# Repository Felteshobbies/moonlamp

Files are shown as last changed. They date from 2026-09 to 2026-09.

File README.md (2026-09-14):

# Moon Lamp

A 3D-printed wall lamp that shows the **real, current phase of the moon**.

**Firmware is developed with the help from AI-**

**Printable files:** [Moon Wall Lamp with Moonphase Simulation](https://www.printables.com/model/1840057-moon-wall-lamp-with-moonphase-simulation)

A ring of RGBW LEDs lights the moon relief from the side. The relief is domed —
it rises 20 mm towards the centre — so light entering from one side is blocked
from reaching the other. That turns a brightness gradient into an actual
terminator, and the crater rims catch light beyond the shadow line exactly the
way they do in photographs of the real moon.

A Raspberry Pi Pico W computes sun and moon positions on the device and drives
the ring. No cloud service, no API key; Wi-Fi is used only to set the clock.

> **Status:** the lamp works. The firmware runs on hardware, and the optical
> and astronomical parts are covered by tests that run on a PC without any
> hardware attached. See [Status](#status) for what is still rough.

---

## Why the dome matters

The original design has a flat relief. With a flat disc, the far side of the
moon still receives about **10 %** of the light from the LEDs opposite — the
disc gets dimmer towards the far edge, but it never goes dark, so every phase
reads as "full moon, unevenly lit".

With the 20 mm dome, the shadow side drops below **0.01 %**. That is the whole
trick, and it is what makes phases legible.

The profile is conical rather than a spherical cap, which turned out to be
better on two counts: the shadow edge is sharper, and a cone is a
[developable surface][dev] — so an already printed flat relief can in principle
be warmed and formed into it, which a spherical cap cannot.

[dev]: https://en.wikipedia.org/wiki/Developable_surface

Those figures come from an optical simulation of the real relief: the STL is
rasterised into a height field, point lights are placed on the ring, and shadows
are cast with a horizon sweep per LED. The dome height, the profile and the
`ARC_TABLE` in the firmware were all chosen from that, not guessed.

---

## Repository layout

| | |
|---|---|
| [`firmware/`](firmware/) | MicroPython for the Pico W: ephemeris, rendering, dithering, PIO LED driver, web interface |
| [`installer/`](installer/) | A single executable that flashes a blank Pico and updates it later |
| [`cad/`](cad/) | FreeCAD sources of the revised frame and the PrusaSlicer projects |
| [`models/`](models/) | Where to get the printable files — **the STLs are not in git**, see [models/README.md](models/README.md) |

The model files are deliberately kept out of version control: together they are
about 1.3 GB and four of them are over GitHub's 100 MB per-file limit. They are
distributed through Printables instead.

---

## The lamp

### Parts

| Part | Notes |
|---|---|
| Raspberry Pi **Pico W** | The W matters — Wi-Fi is needed for the clock |
| SK6812 **RGBW** strip | Roughly 1.35 m. The white channel keeps the moon white; RGB-only looks dirty on grey relief and draws about three times the current |
| 5 V / 4 A supply | 40 RGBW LEDs draw 2.9 A at full white, far less in normal use |
| 74AHCT125 level shifter | **Not optional** — the Pico drives 3.3 V, the strip expects 0.7 × VDD |
| 330 Ω resistor | In series at the level shifter output |
| 1000 µF capacitor | Across the supply at the first LED |
| 3 momentary buttons | Optional — program, brighter, dimmer |

At 33 mm pitch, **40 LEDs** fill the r = 209 mm ring: 1313 mm of circumference
leaves a 26 mm gap at the seam. 39 would leave a visible 59 mm.

Feed 5 V in at **two points**, at the seam and opposite it. That halves the
copper path from 1.31 m to 0.65 m; otherwise the far side is visibly warmer in
white. Pico and strip grounds must be connected.

### Programs

| | | |
|---|---|---|
| P0 | Demo | Every state at speed, one lunation per minute. Needs neither network nor clock |
| P1 | Moon phase | The current phase, visible around the clock |
| P2 | Real moon | Like P1, but only while the moon is actually above your horizon; brightness and colour follow its altitude |
| P3 | Colour cycle | Full moon with a slowly drifting tint, white still carrying it |
| P4 | Night light | The dimmest warm white the hardware can hold across the whole ring |
| P5 | Manual | Moon phase and an explicit red/green/blue/white mix, by hand |
| P6 | Spectrum | The whole colour wheel at full saturation, one turn every seven minutes |
| P7 | Rainbow | The entire spectrum around the ring at once, turning. Everything the strip can do |

Earthshine on the dark side is simulated as well, and a red moon can be
scheduled for eclipse dates.

### Setting it up

On first boot the Pico opens its own Wi-Fi network and serves a setup page —
no cable needed after flashing. After that there is a web interface for
program, brightness, earthshine, ring geometry and output mode.

```bat
python -m pip install mpremote

REM copy the code, then configure from a phone
python firmware\tools\provision.py --port COM5

REM or preset everything right away
python firmware\tools\provision.py --port COM5 --ssid MyNetwork ^
    --password secret --lat 51.2 --lon 6.8 --leds 40
```

Details, wiring and the full parameter list: [firmware/README.md](firmware/README.md).

**Or use the installer.** A single executable takes a factory-fresh Pico all
the way to a running lamp: it flashes MicroPython, writes the firmware, asks for
Wi-Fi and where pixel 0 sits, and opens the lamp in your browser. It carries
everything it needs, so no Python, no `pip` and no network are required. The
same tool updates the lamp later, pulling newer firmware from this repository's
releases. See [installer/README.md](installer/README.md).

Either way it is no rocket science, but some experience with microcontrollers
and electronics is helpful.

---

## Tests

Everything that does not need hardware is tested on a PC:

```bat
python firmware\tests\test_ephemeris.py   REM astronomy against known quantities
python firmware\tests\test_render.py      REM arc shape, colour, dithering
python firmware\tests\test_system.py      REM time zones, config, PIO bit timing
python firmware\tests\test_web.py         REM HTTP parsing, form and route consistency
```

The ephemeris is checked against equinoxes and solstices, the synodic month,
perigee and apogee distances, and the fact that a full moon culminates at
midnight. Long-term drift over 20 years is 0.01 days per lunation.

---

## Status

* The firmware runs on real hardware. Wi-Fi, the web interface, the PIO driver
  and the buttons all work.
* **Temporal dithering over DMA** is implemented but has not been field-tested.
  It is off by default and the lamp falls back to the blocking output path if
  DMA is unavailable.
* There is no over-the-air update yet; new code goes in over USB.
* The installer executable is unsigned, so Windows SmartScreen will warn about
  it. Code signing is the only real fix and costs money; until then the folder
  build and the ZIP are flagged less often than the single file.

---

## License

Two licenses, because this repository holds two different kinds of work:

* **Software** (`firmware/`) — [MIT](LICENSE).
* **Models** (`cad/`, `models/`) — [CC BY-NC-SA 4.0](LICENSE-MODELS.md),
  inherited from the original design.

The lamp is a remix of **Illuminated Moon Wall Lamp** by
[DazedDice](https://www.printables.com/@DazedDice), by way of the
[remix](https://www.printables.com/model/1015789-illuminated-moon-wall-lamp-remix)
by [deimosfr](https://www.printables.com/@deimosfr_1155564). Full attribution
in [LICENSE-MODELS.md](LICENSE-MODELS.md).

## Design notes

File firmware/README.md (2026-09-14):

# Moon Lamp — firmware for the Raspberry Pi Pico W

Drives an SK6812 RGBW ring inside the frame of the domed moon lamp. It computes
the real moon phase from NTP time, maps it to an arc of light and a colour, and
is controlled either by three buttons or from a browser.

> **State of things.** The lamp runs: Wi-Fi, the web interface, the PIO driver
> and the buttons all work on real hardware. The astronomy, frame composition,
> dithering, time zone handling and configuration are plain Python and are
> checked on a PC against known quantities — see [Tests](#tests). The one part
> that has not been through a field test is **temporal dithering over DMA**;
> it is off by default and falls back safely.

---

## Hardware

| Part | Value |
|---|---|
| Controller | Raspberry Pi Pico **W** (Wi-Fi is needed for NTP) |
| LED strip | SK6812 RGBW, GRBW byte order, 33 mm pitch |
| LED count | 40 on the ring (r = 209 mm, 1313 mm circumference, 9° per LED) |
| Level shifter | 74AHCT125 or 74AHCT14 — **mandatory** |
| Data line | 330 Ω in series, right at the level shifter |
| Buffer | 1000 µF across the strip supply at the first LED |
| Power supply | 5 V / 4 A (40 × 4 × 18 mA ≈ 2.9 A at full white) |

At 33 mm pitch, 40 LEDs leave a 26 mm gap at the seam. 39 would leave a visible
59 mm, so 40 is the count the ring wants.

**The level shifter is not a luxury.** The Pico outputs 3.3 V, and the WS28xx
family wants roughly 0.7 × VDD for a logic high. Without one it often works —
but temperature-dependently and unreliably. This is the single most common
reason a rebuild misbehaves.

Feed 5 V in at **two points**: at the seam and at the opposite point of the
ring. That halves the copper path from 1.31 m to 0.65 m; otherwise the far side
is visibly warmer in white.

The Pico and the strip must share a ground connection.

### Default pin assignment (changeable in `config.json`)

| Signal | GPIO |
|---|---|
| LED data | 16 |
| Button: program | 12 |
| Button: brighter | 13 |
| Button: dimmer | 14 |

Buttons switch to ground; the internal pull-ups are enabled, so no external
resistors are needed.

---

## Installation

Flash MicroPython for the Pico W first (UF2 from micropython.org), then:

```bat
python -m pip install mpremote

REM Copy the code only, configure from a phone afterwards
python firmware\tools\provision.py --port COM5

REM Or preset everything right away
python firmware\tools\provision.py --port COM5 ^
    --ssid MyNetwork --password secret ^
    --lat 51.2 --lon 6.8 --utc-offset 1 --leds 40
```

### First-time setup from a phone

With no valid Wi-Fi credentials — or when the **program button is held** during
power-up — the Pico opens a network of its own:

1. Join the Wi-Fi network `Moon Lamp Setup`
2. Open `http://192.168.4.1`
3. Fill in the form and save; the lamp restarts

The ring breathes slowly in blue while this is going on, so the state is
recognisable across the room.

Once connected, the **last octet of the IP address** is blinked out as points of
light on the ring — that way the lamp can be found without opening the router's
interface. The hostname is set over DHCP; whether `moonlamp.local` resolves
depends on your router, and on Windows without Bonjour it usually does not.

---

## Controls

| Button | Short press | Long press |
|---|---|---|
| Program | Next program, acknowledged by N points of light | Calibrate the angle offset |
| Brighter | One brightness step up | |
| Dimmer | One step down | |

Brightness steps: 9 % / 15 % / 25 % / 40 % / 65 % / 100 %, in *perceived*
brightness. They are spaced perceptually rather than linearly, because a linear
scale is unusable at the bottom and wasteful at the top.

The lowest step is set by the hardware, not by taste. With 8 bits per channel,
the dimmest level at which *every* LED still lights is one count — 1/255 of the
light, which is 9 % perceived. Below that the ring does not get dimmer, it
thins out into isolated lit pixels.

### Where pixel 0 sits

Where the first LED of the strip ended up after gluing is known only to whoever
glued it. Without that, the crescent points the wrong way.

**Read the rim like a clock face**, looking at the lamp from the front: 12 at
the top, 3 on the right, 6 at the bottom, 9 on the left. The browser asks for
exactly that, plus whether the LED numbers run clockwise or counter-clockwise
from there — follow the arrow printed on the strip.

The default is **6 o'clock**, because the cable channel leaves at the bottom
and the strip's closing gap is least visible there.

Internally the value is still an angle in degrees (`led_offset`: 0 = right,
90 = top, 180 = left, 270 = bottom), which is what the setup portal and
`provision.py` take. The clock positions are just the readable form of the same
number, and a strip that does not start on an hour can still be trimmed with
the ±1 LED buttons.

#### If you do not know which LED is the first one

Long-press the program button, or press "Find pixel 0" in the browser. A single
point lights up: the LED that the current setting believes sits at **6 o'clock**.
Step it with brighter/dimmer, or with the ±1 LED buttons on the page, until the
lit LED really is at the bottom — then the setting is correct. Press the program
button again to leave. The value is written 10 s later, to spare the flash.

Note what this avoids: you never have to work out which physical LED is number
zero, which is the normal situation once the strip is in the frame.

### Programs

| | Name | Needs network | Needs location |
|---|---|---|---|
| P0 | Demo — every state at speed, one lunation in 60 s | no | no |
| P1 | Moon phase — live phase, always visible | yes | no |
| P2 | Real moon — only while it is actually in the sky | yes | yes |
| P3 | Colour cycle — full moon with a drifting tint | no | no |
| P4 | Night light — warm residual light, whole ring | no | no |
| P5 | Manual — phase and an RGBW mix from the browser | no | no |
| P6 | Spectrum — the full colour range, very slowly | no | no |
| P7 | Rainbow — the whole spectrum around the ring, turning | no | no |

**P3 and P6** are the same idea at two strengths. P3 keeps white as the base
and only tints it, so the disc still reads as a moon; one turn takes 90 s. P6
drives the wheel at full saturation with a 10 % white floor, and takes seven
minutes for a turn — slow enough that you notice it has moved rather than watch
it moving. The difference is the white share: P3 never drops below about 38 %
white, P6 never rises above 10 %.

**P7** is the one program that uses the ring as a ring: every LED carries a
different hue and the wheel turns, twelve seconds to a lap. It only reads as a
rainbow because of the dome — on a flat relief every LED washes across the
whole disc and the colours sum to a muddy white, whereas the 20 mm rise keeps
each LED's light on its own side. Hue follows the physical angle rather than
the pixel index, so it turns the same way round whichever direction the strip
was wired.

**P5** gives you the four channels as sliders — red, green, blue and white
separately, which is the only way to reach the W channel independently — plus
the moon phase from 0 % (new) to 100 % (full) and the direction of the
terminator. Overall brightness stays on the brightness steps, so the sliders
only set the mix between channels. It starts on white alone, which is a plain
white moon.

Worth knowing before you reach for the sliders: **White is a separate LED**,
and on an SK6812 it is roughly as bright as red, green and blue together. With
White at 100 % the colour sliders barely do anything visible — the white simply
swamps them. Pull it down first, or use the one-click mixes above the sliders,
which do that for you.

**P2** fades in with the moon's altitude (off below −2°, full from +8°), makes a
low moon warmer and dimmer and a high one cooler, and dims to 8 % in daylight —
the moon is often up during the day but hardly visible then.

With no network or no clock, P1 and P2 fall back to demo mode rather than
sitting dark.

**Red moon:** list eclipse dates as `"YYYY-MM-DD"` strings under `eclipses` in
`config.json`. Computing real eclipses would be feasible on the Pico but would
fire rarely; the reddening near the horizon in P2 happens every night and uses
the RGBW strip in exactly the same way.

---

## How it works

```
config.json  ──┐
NTP ── time ───┤
               ├──► ephemeris ──► program ──► renderer ──► dither ──► PIO ──► SK6812
buttons ───────┤    phase,        P0…P5       40 pixels    8 bit
HTTP ──────────┘    altitude                  16 bit
```

### Ephemeris (`lib/moonlight/ephemeris.py`)

A Kepler orbit plus the largest perturbation terms, after Paul Schlyter.
Accuracy is around 2 arcminutes; measured long-term drift is **0.01 days per
lunation over 20 years**.

### Renderer (`lib/moonlight/render.py`)

The heart of it is `ARC_TABLE`: which arc of light produces which apparent
illuminated fraction. That table is **not guessed**. It was measured on the
height field of the real relief (`tests/calibrate_arc.py`) and hits the target
value to ±0.005 across the whole range.

An important finding: **real crescents are possible.** For any single azimuth
the shadow boundary does sit at the summit of the dome, i.e. across the middle
of the disc — but because of the 1/d² falloff the near side is far from evenly
lit. A narrow arc lights only a wedge at the rim, and that reads as a crescent.
Measured: an 8° arc gives 9 % apparent illumination.

The arc edges are soft, and the ramp is at least one LED pitch wide. Otherwise
a whole LED would snap in every few hours as the phase advances — in demo mode
you would see 40 discrete steps instead of a moving edge.

**Earthshine:** the unlit side is exactly the complementary phase, and is
lifted to 1.8 % coolly by the LEDs opposite. Ashen moonlight is a real
phenomenon, and the one thing the dome geometry cannot produce by itself.

**Colour:** the W channel carries the base brightness, RGB only the tint. White
mixed from RGB would look dirty on grey relief and would draw roughly three
times the current.

### Dithering (`lib/moonlight/dither.py`)

The most interesting states sit right at the bottom — earthshine at 1.8 %, the
night light at a few percent. Rounded naively to 8 bits you land on counts of 2
to 5, where the steps become visible and white shifts hue as it dims, because
all four channels round differently.

The default is **spatial** dithering around the ring. Neighbouring LEDs
illuminate heavily overlapping areas of the moon, so rounding one up and the
next one down averages out on the surface with no time component at all. The
state is rebuilt for every frame from a fixed starting index, which means a
still image produces bit-identical output frame after frame — nothing can
flicker, by construction, and 60 Hz is plenty.

Measured residual error at the low steps: **0.02 instead of 0.50 of an 8-bit
step.**

Optionally, **temporal dithering** can be switched on from the Output section
of the web page. It engages only while the picture is holding still, and that
restriction is not a detail -- it is the whole difference between the feature
working and actively hurting. Building six subframes costs six dithers, 32 ms
on this chip against 13 ms for the picture itself. On a moving programme the
loop then never finishes early, `tick()` runs once per frame instead of dozens
of times, and the six subframes are shown for 50 ms each: that does not
average, it strobes, and a drifting rainbow lurches around the ring in thirds
of a second.

So the driver asks a cheaper question instead: has the frame stopped changing?
A moon phase holds the same 16-bit values for minutes, so its subframes are
built once and then cycle for as long as that lasts -- exactly the case they
help. Anything moving gets a single dither, no worse than the blocking path and
still over DMA, so the CPU is never held with interrupts off. The status page
says which of the two it is doing. It splits each frame into several subframes whose time average
resolves finer than a single count, which buys about three extra bits exactly
where they are needed, and makes individual LEDs fade in smoothly instead of
snapping on. That needs the DMA output path: the CPU only starts the transfer
and a DMA channel feeds the PIO FIFO, so the output costs no CPU time. If DMA
cannot be set up the lamp says so and stays on the blocking path — the setting
never takes the lamp down.

The spatial pattern would only be visible right in front of the LEDs in the
outermost ring, and the frame's front lip hides that anyway.

### LED driver (`lib/moonlight/leds.py`)

The PIO state machine generates the one-wire timing exactly and without jitter,
whatever the CPU is doing. 12 PIO cycles per bit at 10 MHz gives T0H 0.30 /
T0L 0.90 / T1H 0.60 / T1L 0.60 µs.

The obvious shortcut is to reuse the WS2812B numbers, but the SK6812 wants a
symmetric one bit; with WS2812B timing both halves sit outside the window, and
the shortest pulse — the 0.25 µs high of a zero — is the first thing a marginal
driver loses.

The transmit FIFO is joined (`JOIN_TX`), doubling it from four words to eight.
One word is one pixel and takes 38.4 µs to shift out, so the buffer grows from
154 µs to 307 µs. That matters because the strip latches after 80 µs of idle:
if the FIFO ever runs dry mid-frame, the remaining pixels are written to LED 0
onwards and the first LEDs flash.

On the blocking path the frame is pushed with interrupts disabled. That costs
about a tenth of the CPU at 60 Hz and is invisible to Wi-Fi, whereas an
underrun is immediately visible on the ring.

---

## Tests

All of these run on a PC under CPython, with no Pico attached:

```bat
python firmware\tests\test_ephemeris.py     REM astronomy against known quantities
python firmware\tests\test_render.py        REM frame composition, colour, dithering
python firmware\tests\test_system.py        REM time zone, configuration, programs
python firmware\tests\test_web.py           REM HTTP parsing, forms, routes
```

`test_ephemeris.py` checks, among other things, equinoxes and solstices to
0.01°, perigee and apogee distances, the spread of lunations against the real
range of 29.27–29.83 d, long-term drift over 20 years, and that a full moon
culminates at midnight.

`test_system.py` also parses the PIO assembly and compares the literals in it
against the timing constants in the same module, because `asm_pio()` runs its
body in a namespace of its own where module-level names are invisible. The two
therefore cannot drift apart unnoticed.

`ARC_TABLE` in `render.py` is the one thing this suite does not re-derive.
Reproducing it needs the STL of the relief, numpy, and the optical simulation
it was measured with. What the tests do check is that the values behave: the
arc grows monotonically with the illuminated fraction, the edges stay soft, and
nothing jumps as the azimuth or the phase moves.

---

## The browser interface

Once the lamp is on the network it is reachable at the IP that `status.py`
reports, e.g. `http://192.0.2.42/`. The page refreshes itself every 30
seconds and follows the light or dark system theme.

It shows the running program, brightness, signal strength, IP, local time and
date, the moon phase with its age and distance, and the moon's altitude above
the horizon. You can set the program, the brightness step, the earthshine
level, the ring geometry, the output mode, and manual mode P5 with its
illuminated fraction, direction and warmth.

Three device actions sit at the end of the page:

| Link | Effect |
|---|---|
| Find the angle | Starts the same mode as a long press on the program button |
| Restart | Soft reset |
| Forget Wi-Fi | Clears the credentials and reopens the setup portal |

The page computes nothing itself: `main.py` gathers the values in
`build_info()` and hands them over ready-made, so that loading the page does
not disturb the frame rate.

For tweaking the appearance without a device, a rendered sample sits in
`tests/control_page_sample.html`.

---

## Reading the status

```bat
python firmware\tools\status.py            REM finds the port by itself
python firmware\tools\status.py --scan     REM also lists networks in range
```

This prints the configuration, the Wi-Fi status in plain words, IP, gateway,
RSSI, the URL of the control page and the clock that was set. The call briefly
interrupts the running program and restarts it afterwards (`--no-reset`
suppresses that).

The CYW43 status codes are unusable without translation:

| Code | Meaning |
|---|---|
| `3` | Got an IP, all good |
| `-1` | Link down |
| `-2` | Joining — stays here when the SSID does not match |
| `-3` | Authentication failed, usually the password |
| `-4` | Network not found |

**Wi-Fi names are case-sensitive.** `mynetwork` and `MyNetwork` are two different
networks. Mistype that in the portal and the station sits at `-2`, which looks
like a password problem. `connect()` now catches this itself: if the scan finds
a network that differs only in spelling, it corrects the configuration and
reconnects. The REPL then shows:

```
Wi-Fi: no luck, status -2 (joining)
Wi-Fi: in range this network is called 'MyNetwork', not 'mynetwork' -- correcting and saving
Wi-Fi: connected as 192.0.2.42 , -36 dBm -> http://192.0.2.42/
```

To follow along live: `mpremote connect COM5 repl` (Ctrl-D restarts).

---

## When something does not work

| Symptom | Cause |
|---|---|
| Wrong colours | Byte order — `leds.py` writes GRBW; swap there for other strips |
| First LEDs fine, rubbish further along | Level shifter missing, or grounds not connected |
| White turns yellowish towards the far side | Voltage drop, the second feed point is missing |
| The first LEDs flash during updates | FIFO underrun — check that `JOIN_TX` is active and interrupts are disabled on the blocking path |
| Crescent points the wrong way | Calibrate the angle offset, and check `led_clockwise` |
| The lamp stays in demo mode | No NTP time — check Wi-Fi |
| The portal does not appear | Hold the program button while powering up |

### When the upload does not work

`provision.py` checks in advance whether a MicroPython REPL actually answers on
the port, and names the reason if not. By far the most common case with a new
board:

**There is no MicroPython on the Pico yet.** A factory-fresh board, or one
flashed with the C SDK, does enumerate over USB but has no REPL for `mpremote`
to talk to. The USB identifier gives it away:

| USB ID | Meaning |
|---|---|
| `2E8A:0003` | BOOTSEL mode, drive `RPI-RP2` |
| `2E8A:0005` | **MicroPython** — the upload only works with this |
| `2E8A:000A` | A program built with the C SDK, no MicroPython |

Installing MicroPython:

1. Unplug the Pico
2. Hold BOOTSEL and plug it in while holding
3. The drive `RPI-RP2` appears. `INFO_UF2.TXT` on it names the board, in case
   it is unclear which one is plugged in
4. Copy the `RPI_PICO_W-*.uf2` build onto the drive
5. The Pico restarts and enumerates as `2E8A:0005`

For Wi-Fi you need the **W variant** (`RPI_PICO_W`, or `RPI_PICO2_W` on a
Pico 2 W) — without the W there is no radio driver and `import network` fails.
The build this was developed against is `RPI_PICO_W-20260824-v1.29.0.uf2`; get
it from [micropython.org/download](https://micropython.org/download/).

List the attached boards:

```bat
python -c "import serial.tools.list_ports as l; [print(p.device, hex(p.vid or 0), p.description) for p in l.comports()]"
```

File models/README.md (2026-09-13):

# Models

**The printable files are not in this repository.** Together they are about
1.3 GB, and four of them exceed GitHub's hard 100 MB limit for a single file.
Git LFS would not help either: the free allowance is 1 GB of storage and 1 GB
of traffic per month, which a handful of clones would exhaust.

They are published on Printables instead:

**[Moon Wall Lamp with Moonphase Simulation](https://www.printables.com/model/1840057-moon-wall-lamp-with-moonphase-simulation)**

## What you need to print

| Part | Notes |
|---|---|
| Moon relief, domed | Two halves for a 360 × 360 bed, or four quarters for smaller printers |
| Frame segments | Click together; a variant with fewer seams is included for the Prusa XL |
| Mounting brackets | |
| Back support | Optional |

The relief has a 60 × 60 × 3 mm pocket in the centre of its underside for the
electronics, with two 4 × 4 mm cable channels crossing it at 90° so the cable
can leave in any of four directions. The channels have 30° flanks and print
without support.

| File | Bounding box |
|---|---|
| Whole domed relief | 416.5 × 416.5 mm |
| Halves | 355.4 × 355.4 mm |
| Quarters | 294.3 × 208.2 mm |

## Printing notes

* The back stays flat on the bed — no supports needed anywhere.
* Drop the infill to **5–8 %**. The dome adds roughly 790 cm³ of enclosed
  volume that carries no load; at 15 % that is several hundred grams of PLA and
  many extra hours per part.
* The XY outline is unchanged from the original design, so the frame fits
  either relief, flat or domed.
* At a 20 mm dome height the summit sits practically flush with the 28 mm deep
  front edge of the frame.

## License

These models are derived work under **CC BY-NC-SA 4.0**. See
[LICENSE-MODELS.md](../LICENSE-MODELS.md) for the attribution chain and what
the license requires of you.

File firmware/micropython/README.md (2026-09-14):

# MicroPython

`RPI_PICO_W-20260824-v1.29.0.uf2` is an unmodified MicroPython build for the
Raspberry Pi Pico W, taken from [micropython.org/download](https://micropython.org/download/RPI_PICO_W/).

It is in version control on purpose. The installer's whole promise is that it
carries everything needed to take a blank Pico to a running lamp with no
network — and a build runner starting from a fresh checkout has no other way to
obtain it. Downloading it during the build would put micropython.org in the
critical path of every release.

MicroPython is copyright Damien P. George and contributors, and is distributed
under the MIT license. Redistributing the binary is permitted; the full license
travels with the project at
[github.com/micropython/micropython](https://github.com/micropython/micropython/blob/master/LICENSE).

For a **Pico 2 W** you need the `RPI_PICO2_W` build instead — a UF2 carries a
family id and the bootloader silently discards one meant for the other chip.
The installer checks for that mismatch and refuses rather than leaving you with
a board that never comes back. Pass a different build with `--uf2`.

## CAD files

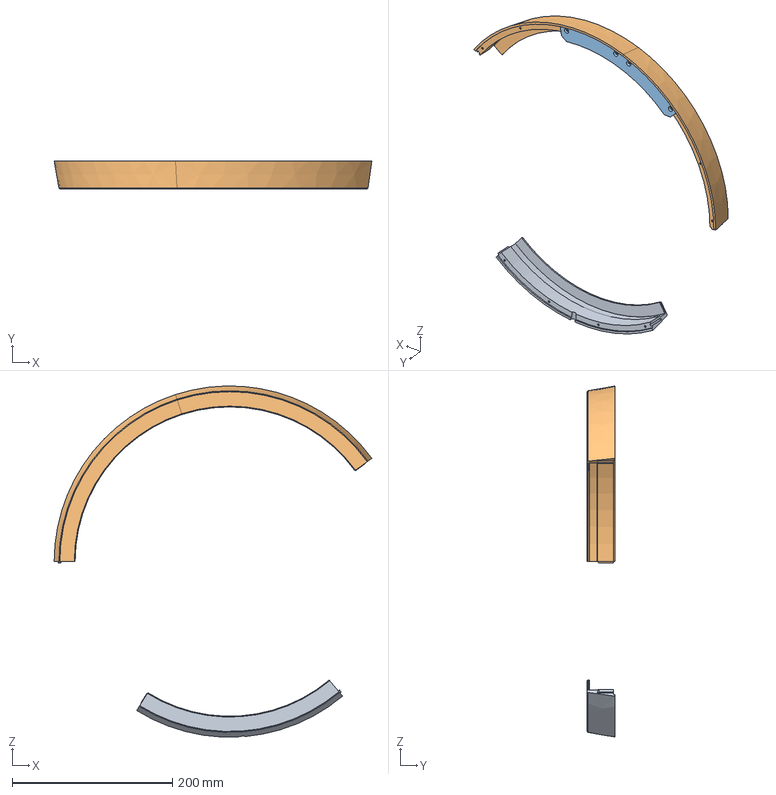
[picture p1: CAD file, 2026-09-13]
cad/framev3.FCStd
396.2 x 35.0 x 437.7 mm
frameCable1x
frameXL2x
mount3x

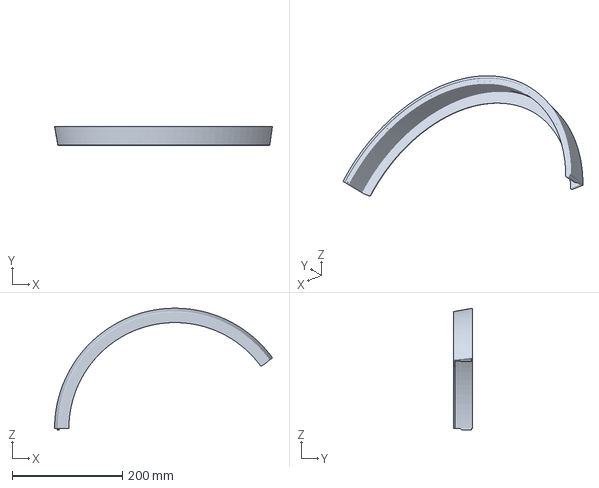
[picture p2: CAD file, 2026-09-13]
cad/framev3-frameXL2x.3mf
396.2 x 35.0 x 221.0 mm

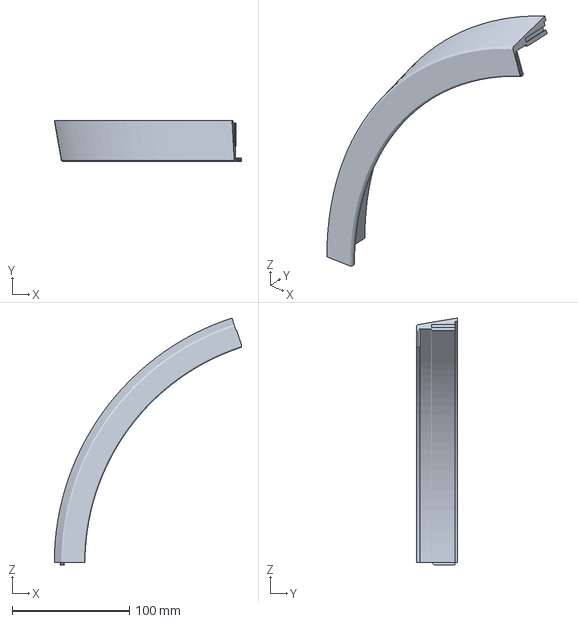
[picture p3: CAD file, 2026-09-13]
cad/framev3-frame4x.3mf
159.6 x 35.0 x 210.3 mm

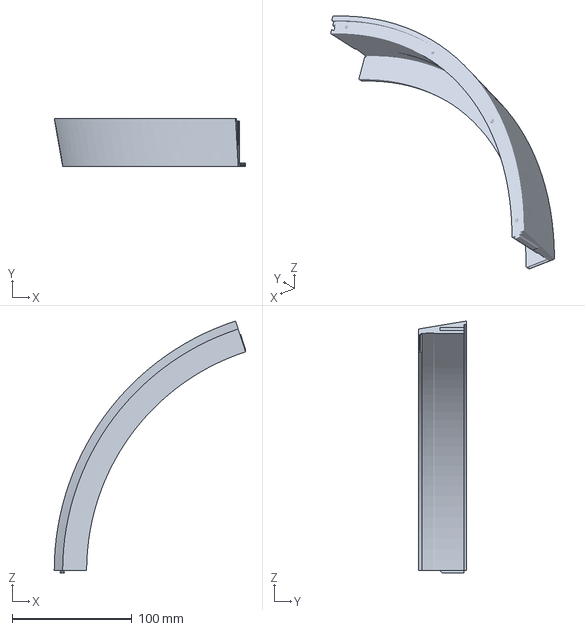
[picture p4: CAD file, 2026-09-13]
cad/frame-body.3mf
159.9 x 40.0 x 210.3 mm

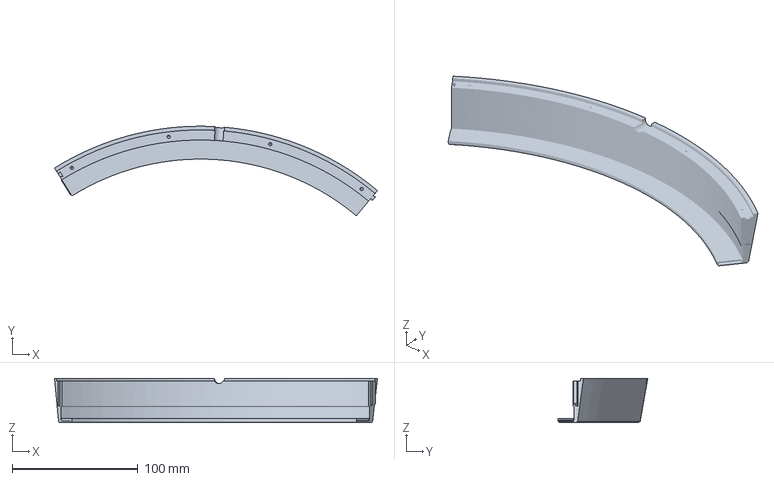
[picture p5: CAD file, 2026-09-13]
cad/framev3-frameCable1x.3mf
256.8 x 71.3 x 35.0 mm

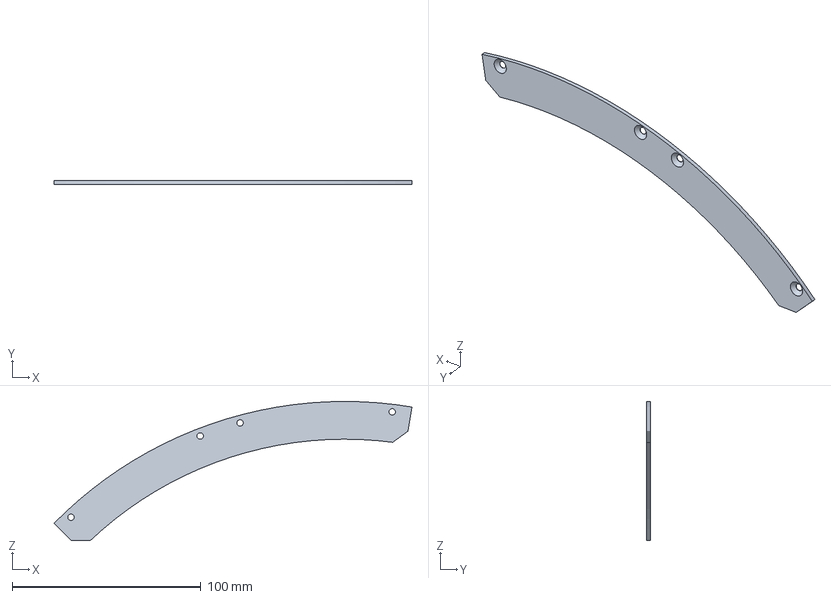
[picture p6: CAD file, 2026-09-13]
cad/framev3-mount3x.3mf
189.7 x 2.00 x 73.7 mm

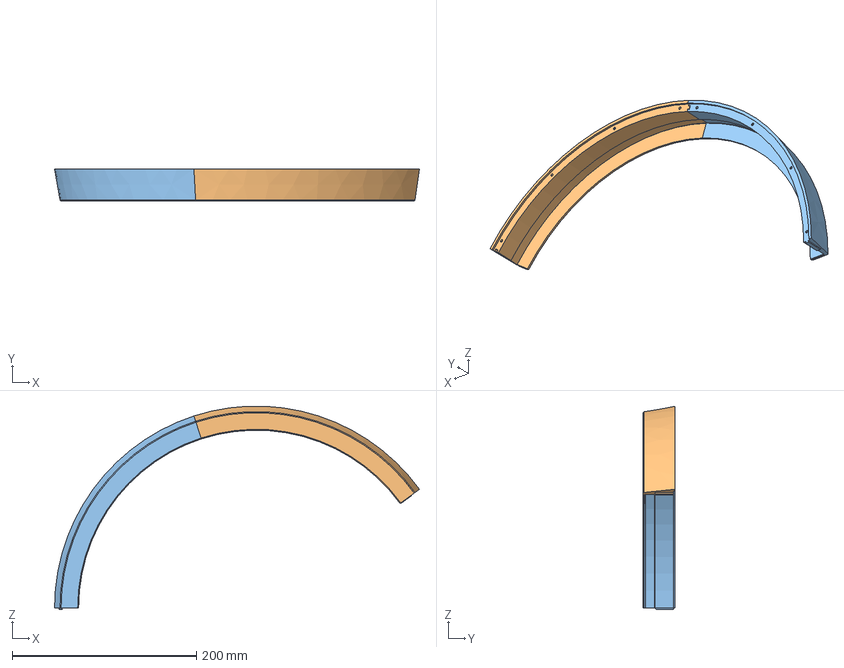
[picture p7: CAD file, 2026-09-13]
cad/frame.FCStd
396.2 x 35.0 x 220.8 mm
Körper

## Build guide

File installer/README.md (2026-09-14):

# Moon Lamp Installer

Takes a Raspberry Pi Pico W from factory-fresh to a running lamp, and updates
one later. A single executable with no Python, no `pip` and no network needed —
it carries both the firmware and a MicroPython build inside it.

```
moonlamp-installer              opens the window
moonlamp-installer status       what is attached and what is on it
moonlamp-installer install      flash and set up a board
moonlamp-installer update       newest firmware, settings kept
moonlamp-installer restart      restart the lamp, change nothing
moonlamp-installer config       show the lamp's settings, change none
moonlamp-installer version      what this build carries
moonlamp-installer releases     what has been published
```

## What it does

1. Finds the board by its USB identifier, and says which state it is in —
   BOOTSEL, MicroPython, or something else entirely.
2. If MicroPython is missing, walks you through BOOTSEL and copies the UF2
   across. That really is all flashing is: the bootloader appears as a drive
   and reboots once it has a complete image.
3. Writes the firmware over the serial port.
4. Asks for Wi-Fi, location, LED count and **where pixel 0 sits, as a clock
   position** — the same way the lamp's own web page asks.
5. Restarts the lamp, finds its address and offers to open it.

### What the bootloader can and cannot tell us

`INFO_UF2.TXT` on the BOOTSEL drive names the chip family, and that is checked
before anything is written: a UF2 carries a family id and the bootloader
silently discards blocks that do not match, so flashing an RP2040 build onto a
Pico 2 does nothing at all and the board just never comes back. Refusing up
front with an explanation is far kinder than that silence.

What it cannot tell us is whether the board has a radio. An RP2040 bootloader
reports `Board-ID: RPI-RP2` for a Pico and a Pico W alike, so any attempt to
spot the W there raises a false alarm on every Pico W there is. That question is
therefore settled afterwards, by asking the running MicroPython whether
`network` imports — and if it does not, the installer says so plainly, because
a lamp without Wi-Fi never gets the time and sits in demo mode for ever.

The update path compares what is on the board against both the copy inside the
installer and the newest release on GitHub, and offers whichever is newer.
Settings are never touched by an update.

### Settings are read before they are written

The settings form is pre-filled with sensible defaults, and defaults are
precisely what must not land on a lamp that is already configured. So the
current `config.json` is read off the board as soon as one with firmware is
found, the form shows those values, and **only fields you actually changed are
written back**. A confirmation lists them by name before anything is sent.

A blank field never means "erase this". That matters most for the password: it
would otherwise take the lamp off the network on a stray save, and the mistake
would only show up minutes later when the clock failed to set.

`moonlamp-installer config` prints what is on the lamp and changes nothing.

"Save and restart" restarts the lamp even when nothing needed writing. The
button names two things, and one that quietly does neither is worse than one
that does the harmless half.

## Why it does not use mpremote

`provision.py` drives `mpremote` as a subprocess, which is fine from a source
checkout and impossible once frozen: in a one-file build `sys.executable` is
the executable itself, so `[sys.executable, "-m", "mpremote"]` relaunches the
installer. [`device.py`](moonlamp_installer/device.py) therefore speaks the
MicroPython raw REPL protocol directly. It is about 150 lines and has the
pleasant side effect of removing a moving dependency from a tool whose entire
job is to work on a machine we know nothing about.

## Building

```bat
python -m pip install pyinstaller pyserial
python installer\build.py
```

The result is `installer/dist/moonlamp-installer.exe`, around 11 MB. The
firmware is staged into the package first rather than referenced in place, so
an executable always carries exactly what was in the repository when it was
built — an installer that quietly picked up a half-edited working tree would be
worse than none.

`--onedir` builds a folder instead of a single file. That starts faster and is
flagged less often by antivirus software, at the cost of not being one file.

### About the antivirus problem

Unsigned one-file PyInstaller executables are routinely flagged by Windows
SmartScreen and sometimes quarantined outright by antivirus software. This is
not a rare edge case, and for a tool that writes firmware to hardware it is a
bad first impression. The only reliable fix is a code signing certificate
(200–400 € a year). Without one, expect to tell people to click through
"Windows protected your PC", which is itself poor advice to be giving.

The `--onedir` build and a plain ZIP are flagged noticeably less often.

## Testing

```bat
python installer\tests\test_installer.py
```

Runs without a Pico. It covers version comparison, the release archive format,
update decisions when GitHub is unreachable, and the REPL file transfer against
a fake serial port — that last one caught a real bug where the read loop
discarded whatever arrived in the same packet as the token it was waiting for,
which is exactly how a real device answers.

It also checks that the installer's copy of the clock-position conversion still
matches the firmware's. The installer cannot import the firmware at runtime —
it is what puts it there — so that conversion is duplicated on purpose, and the
test is what stops the copy drifting.

## Requirements from source

Python 3.7 or newer and `pyserial`. tkinter for the window, which ships with
Python on Windows and macOS; on Linux it is usually a separate package
(`python3-tk`). Without it the console commands still work.

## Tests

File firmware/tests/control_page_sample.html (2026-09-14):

# Moon lamp

connected to MyNetwork · 192.0.2.42 · -36 dBm

Program

P2 Real moon

Brightness

40.0 %

Signal

-36 dBm

IP

192.0.2.42

Local time

22:14

Date

2026-09-13

Moon phase

63 % waning

Moon age

18.7 days

Distance

391240 km

Moon altitude

+21.4 deg above the horizon

Uptime

143 min

## Program

P0 · DemoEvery mode at high speed, a whole month in a minute. Needs neither network nor clock.P1 · Moon phaseThe current moon phase, visible around the clock.P2 · Real moonLike P1, but only while the moon is actually up. Brightness and colour follow its altitude.P3 · Colour cycleFull moon with a slowly drifting tint. White still carries it, so the disc stays a moon.P4 · Night lightThe dimmest possible warm white across the whole ring.P5 · ManualPhase and colour by hand: four channel sliders and an illuminated fraction.P6 · SpectrumThe whole colour wheel at full saturation, one turn every seven minutes.P7 · RainbowThe entire spectrum around the ring at once, turning. Everything the strip can do.

## Brightness

9 %15 %25 %40 %65 %100 %

## Earthshine

Glow on the dark side 1.8 %Apply

The averted half of the real moon is lit faintly by earthlight. 0 turns it off. On the lower brightness steps it is dropped automatically, because a glow weaker than one count would only show as scattered pixels.

## Manual — switches to P5

WhiteWarmRedAmberGreenCyanBlueMagenta

Moon phase 50 %DirectionRed 0 %Green 0 %Blue 0 %White 100 %Apply

0 % is new moon, 100 % is full. Overall brightness comes from the steps above, so the sliders only set the mix between channels.

White is a separate LED, and on an SK6812 it is about as bright as red, green and blue together. With White at 100 % the colours barely show — pull it down to see them. The buttons above do that for you.

## Ring

Pixel 0 sits atCounting from thereApply

−1 LED+1 LEDFind pixel 0

Look at the lamp from the front and read the rim like a clock face: 12 at the top, 3 on the right, 6 at the bottom, 9 on the left. Set where the first LED of the strip sits, then whether the numbers run clockwise or counter-clockwise from it — follow the arrow printed on the strip.

Not sure which LED is the first one? Press “Find pixel 0”. One LED lights: the one this setting believes is at 6 o’clock. Nudge by ±1 LED until the lit one really is at the bottom — then the setting is right, and you never had to count a single LED. Press the program button on the device, or pick a program here, to leave that mode again.

Currently 270°. One LED is 9.0° on this ring.

Number of LEDs Apply and restart

Changing the count restarts the lamp: the output buffer is allocated once at start-up.

## Output

Temporal ditheringSubframes 8Apply and restart

Currently running: blocking. Temporal dithering shows several slightly different frames in quick succession; the eye averages them, which adds about three bits and makes single LEDs fade in smoothly at the low brightness steps. It needs the DMA path – if that is unavailable the lamp falls back automatically and says so here.

## Device

RestartForget Wi-Fi

This page refreshes every 30 seconds. Firmware 0.2-dev.

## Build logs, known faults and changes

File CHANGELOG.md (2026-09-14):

# Changelog

## 0.2.1 — 2026-09-14

* **Temporal dithering no longer fights the animations.** It used to build its
  subframes on every frame -- six dithers, 32 ms against 13 ms for the picture
  -- so the loop never finished early, `tick()` ran once per frame rather than
  dozens of times, and the six subframes were each shown for 50 ms. That is not
  averaging, it is strobing, and a drifting rainbow lurched around the ring in
  thirds of a second. The driver now builds subframes only once a frame has
  held still for three passes, and gives anything moving a single dither. The
  status page says which of the two it is doing.

## 0.2 — 2026-09-14

* **P7 Rainbow**, a new program: the whole spectrum around the ring at once,
  turning, forty seconds to a lap. The only program that uses the ring as a
  ring, and it works because the dome keeps each LED's light on its own side --
  on a flat relief the colours would sum to a muddy white.
* **Animations no longer step once a second.** Programme time came from
  `time.time()`, which on MicroPython returns whole seconds as an integer, so
  every animated programme advanced in one-second jumps -- three LED positions
  at a time on the rainbow. It now accumulates from `ticks_ms()`, which also
  avoids that counter's own wrap. P0, P3, P6 and P7 were all affected; it was
  simply most visible on the fastest one.
* **The colour wheel is now constant in power**, the way the Adafruit
  strandtest wheel is. Saturating a cosine wheel gives the right hues but makes
  the six pure primaries a third dimmer than the blends between them -- visible
  as bands around the ring and as a pulse while it turns. P6 and P7 both use
  the new ramp; P3 never needed it, because the unsaturated cosine wheel sums
  to a constant on its own.
* **Manual mode gained one-click colour mixes.** The four sliders were correct
  all along but looked dead: White starts at 100 %, and an SK6812's white die
  is about as bright as the other three together, so raising Red changed almost
  nothing visible. The presets pull White down, and the page now says why.
* **An installer**, as a single executable. It takes a blank Pico from BOOTSEL
  to a running lamp -- MicroPython, firmware, Wi-Fi, location, pixel 0 -- and
  updates it afterwards from this repository's releases. It carries the
  firmware and a MicroPython build inside it, so it needs no network.
  It speaks the raw REPL protocol directly rather than driving mpremote, which
  cannot work once frozen: `sys.executable` is then the executable itself.
* **P6 Spectrum**, a new program: the full colour wheel at saturation, one turn
  every seven minutes. The counterpart to P3, which stays muted on purpose.
* **P3 Colour cycle** is less timid. The coloured share went from 45 % to 62 %,
  because the old setting did not read as a colour change from across a room.
* **P5 Manual** reworked. Warmth is gone, replaced by four channel sliders --
  red, green, blue and white -- which is the only way to address the W channel
  on its own. The phase is now stated plainly as 0 to 100 %.
* **Pixel 0 is set as a clock position** rather than an angle in degrees: 12 at
  the top, 3 right, 6 bottom, 9 left, read off the lamp from the front. Degrees
  remain the stored form and the portal still takes them.

## 0.1 — 2026-09-13

First release of the firmware. It runs the lamp: Wi-Fi, web interface, PIO LED
driver and buttons all work on hardware.

### What it does

* Computes sun and moon positions on the device — no cloud service, no API key.
  Wi-Fi is used only to set the clock over NTP.
* Six programs: demo, live moon phase, real moon gated on the moon's actual
  altitude, colour cycle, night light, manual.
* Simulates earthshine on the dark side, warms and dims a low moon, and can be
  given eclipse dates for a red moon.
* Set up from a phone: on first boot the Pico opens its own network and serves
  a setup form. After that, a web interface for program, brightness,
  earthshine, ring geometry and output mode.
* Three optional buttons do the same on the device.
* PC-side scripts to provision a board over USB and to read its status.

### Notable details

* The arc-to-phase mapping (`ARC_TABLE`) was measured on the height field of
  the real relief, not guessed. An 8° arc gives 9 % apparent illumination,
  which is what makes real crescents possible on a convex dome.
* SK6812 timing is generated by the RP2040's PIO at 12 cycles per bit. The
  WS2812B numbers do not fit: the SK6812 wants a symmetric one bit, and the
  0.25 µs high of a zero is the first thing a marginal driver loses.
* The transmit FIFO is joined, which grows the buffer from 154 µs to 307 µs.
  The strip latches after 80 µs of idle, so an underrun would write the rest of
  the frame to LED 0 onwards and make the first LEDs flash.
* Dithering is spatial around the ring rather than temporal, so a still image
  is bit-identical frame after frame and cannot flicker. Residual error at the
  low brightness steps is 0.02 of an 8-bit step instead of 0.50.
* The ephemeris is checked against equinoxes and solstices to 0.01°, against
  perigee and apogee distances, and against the fact that a full moon culminates
  at midnight. Long-term drift is 0.01 days per lunation over 20 years.

### Known limitations

* **Temporal dithering over DMA** is implemented but has not been field-tested.
  It is off by default; if DMA cannot be set up the lamp says so on the status
  page and stays on the blocking output path.
* There is no over-the-air update. New code goes in over USB with `mpremote`.
* `moonlamp.local` depends on your router. On Windows without Bonjour it
  usually does not resolve — the lamp blinks the last octet of its IP on the
  ring instead.

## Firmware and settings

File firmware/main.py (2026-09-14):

"""Moon lamp -- main loop.

Startup sequence:
  1. Load the configuration. If Wi-Fi is missing, or the program button is
     held down at power-on, the Pico opens its own network and shows the
     setup form.
  2. Join the Wi-Fi, set the clock over NTP, blink the IP on the ring.
  3. From then on the loop runs at a fixed frame rate: poll the buttons,
     compute a frame, dither it, emit it, and serve HTTP alongside.

Without a network or without a clock the lamp keeps running -- it falls
back to demo mode rather than staying dark.
"""

import sys
import time

sys.path.insert(0, "lib")

from moonlight import buttons as buttonsmod          # noqa: E402
from moonlight import config as configmod
from moonlight import ephemeris                       # noqa: E402            # noqa: E402
from moonlight import leds as ledsmod                # noqa: E402
from moonlight import programs                       # noqa: E402
from moonlight import render                         # noqa: E402
from moonlight import timeutil                       # noqa: E402
from moonlight import web                            # noqa: E402

SAVE_DELAY_MS = 10_000        # only write to flash once things have settled
AP_NAME = "Moon Lamp Setup"


def ticks_ms():
    return time.ticks_ms() if hasattr(time, "ticks_ms") else int(time.time() * 1000)


def ticks_diff(a, b):
    return time.ticks_diff(a, b) if hasattr(time, "ticks_diff") else a - b


# ------------------------------------------------------------------ Feedback

def flash_count(ring, cfg, count, colour=None, on_ms=180, off_ms=140):
    """Flash `count` points of light -- feedback without a display."""
    n = cfg["led_count"]
    px = colour or render.tint(0.35)
    for k in range(count):
        frame = [(0, 0, 0, 0)] * n
        idx = render.pixel_at_angle(n, render.CALIBRATION_ANGLE,
                                    cfg["led_offset"], cfg["led_clockwise"])
        for j in range(k + 1):
            frame[(idx + j * 2) % n] = px
        ring.show(frame)
        time.sleep_ms(on_ms) if hasattr(time, "sleep_ms") else time.sleep(on_ms / 1000)
        ring.show([(0, 0, 0, 0)] * n)
        time.sleep_ms(off_ms) if hasattr(time, "sleep_ms") else time.sleep(off_ms / 1000)


def show_ip(ring, cfg, ip):
    """Last octet of the IP as blinks -- so the Pico can be found without a router."""
    try:
        last = int(ip.split(".")[-1])
    except (ValueError, IndexError):
        return
    for digit in str(last):
        flash_count(ring, cfg, int(digit) if digit != "0" else 10,
                    colour=render.tint(0.3, coolness=1.0))
        time.sleep(0.4)


# ------------------------------------------------------------------- Network

def start_ap(cfg):
    import network
    ap = network.WLAN(network.AP_IF)
    ap.config(essid=AP_NAME, security=0)
    ap.active(True)
    while not ap.active():
        time.sleep(0.2)
    return ap


# Plain text for the CYW43 status codes. Without this the REPL just shows
# "-2", and you cannot tell a wrong password from a missing network.
WLAN_STATUS = {
    0: "idle", 1: "connecting", 2: "wrong password", 3: "got IP",
    -1: "link down", -2: "joining",
    -3: "join rejected (password?)", -4: "network not found",
    -5: "connection failed",
}


def _status_text(wlan):
    try:
        s = wlan.status()
    except Exception:
        return "?"
    return "%s (%s)" % (s, WLAN_STATUS.get(s, "unknown"))


def match_ssid(wlan, want):
    """Look for a network that differs only in upper/lower case.

    Wi-Fi names are case sensitive. Get that wrong in the setup form and the
    station sits silently at "joining" -- a symptom that looks exactly like a
    password problem.
    """
    try:
        found = []
        for n in wlan.scan():
            s = n[0].decode("utf8", "ignore")
            if s and s not in found:
                found.append(s)
    except Exception as exc:
        print("  scan not possible:", exc)
        return None, []
    if want in found:
        return want, found
    for s in found:
        if s.lower() == want.lower():
            return s, found
    return None, found


def connect(cfg, timeout=20):
    import network
    wlan = network.WLAN(network.STA_IF)
    wlan.active(True)
    try:
        wlan.config(hostname=cfg["hostname"])
    except (AttributeError, OSError, ValueError):
        pass

    ssid = cfg["ssid"]
    print("Wi-Fi: connecting to %r ..." % ssid)
    wlan.connect(ssid, cfg["password"])
    t0 = time.time()
    while not wlan.isconnected() and time.time() - t0 < timeout:
        time.sleep(0.3)

    if not wlan.isconnected():
        print("Wi-Fi: no luck, status %s" % _status_text(wlan))
        real, found = match_ssid(wlan, ssid)
        if real and real != ssid:
            print("Wi-Fi: in range this network is called %r, not %r -- "
                  "correcting and saving" % (real, ssid))
            cfg["ssid"] = real
            try:
                configmod.save(configmod.validate(cfg))
            except Exception as exc:
                print("Wi-Fi: saving failed:", exc)
            wlan.disconnect()
            time.sleep(1)
            wlan.connect(real, cfg["password"])
            t0 = time.time()
            while not wlan.isconnected() and time.time() - t0 < timeout:
                time.sleep(0.3)
        elif not real:
            print("Wi-Fi: %r is not in range. Found: %s"
                  % (ssid, ", ".join(found) if found else "nothing"))

    if wlan.isconnected():
        ip = wlan.ifconfig()[0]
        try:
            rssi = " , %d dBm" % wlan.status("rssi")
        except Exception:
            rssi = ""
        print("Wi-Fi: connected as %s%s -> http://%s/" % (ip, rssi, ip))
        return wlan

    print("Wi-Fi: giving up, status %s -- the lamp continues in demo mode"
          % _status_text(wlan))
    return None


# -------------------------------------------------------------------- Portal

def run_portal(cfg, ring):
    """Setup mode: own network, form, then restart."""
    start_ap(cfg)
    server = web.Server()
    pulse = 0.0
    state = {"done": False, "msg": ""}

    def handler(path, query):
        if path != "/save":
            return "200 OK", "text/html", web.portal_page(cfg, state["msg"])

        # An empty form means the request body never arrived. That must not
        # pass silently as "saved", or the lamp restarts without credentials
        # and nobody knows why.
        if not query:
            print("Portal: POST /save with no form data")
            return ("200 OK", "text/html",
                    web.portal_page(cfg, "The form data did not arrive. "
                                         "Please submit again."))

        for key, _, _ in web.PORTAL_FIELDS:
            if key in query and query[key] != "":
                cfg[key] = query[key]
        if "password" in query:
            cfg["password"] = query["password"]      # may be empty (open network)

        for key in ("latitude", "longitude", "led_offset"):
            try:
                cfg[key] = float(cfg[key])
            except (TypeError, ValueError):
                pass
        for key in ("utc_offset", "led_count"):
            try:
                cfg[key] = int(float(cfg[key]))
            except (TypeError, ValueError):
                pass

        if not cfg.get("ssid"):
            return ("200 OK", "text/html",
                    web.portal_page(cfg, "A Wi-Fi network name is required."))

        configmod.save(configmod.validate(cfg))
        # Read back: only restart if it really landed in the filesystem.
        # Otherwise you end up in an endless loop of portal, save, restart.
        back = configmod.load()
        if back.get("ssid") != cfg["ssid"]:
            print("Portal: could not write config.json")
            return ("200 OK", "text/html",
                    web.portal_page(cfg, "Saving failed -- check the Pico's "
                                         "filesystem."))
        print("Portal: saved for SSID %r, restarting" % cfg["ssid"])
        state["done"] = True
        return ("200 OK", "text/html",
                web.portal_page(cfg, "Saved for '%s'. The lamp will restart "
                                     "and connect." % cfg["ssid"]))

    while True:
        server.poll(handler)
        # A slow breathing pulse signals setup mode
        pulse += 0.02
        level = 0.05 + 0.05 * (1.0 + _sin(pulse)) / 2.0
        ring.show(render.solid(cfg["led_count"],
                               render.tint(level, coolness=1.0)))
        if state["done"]:
            time.sleep(1.5)
            _reset()
        time.sleep(0.02)


def _sin(x):
    import math
    return math.sin(x)


def _reset():
    try:
        import machine
        machine.reset()
    except ImportError:
        raise SystemExit(0)


# ---------------------------------------------------------------------- Main

def main():
    cfg = configmod.load()
    ring = ledsmod.Ring(cfg["led_pin"], cfg["led_count"],
                        temporal=cfg.get("temporal", False),
                        n_subframes=int(cfg.get("subframes", 8)))
    panel = buttonsmod.Panel(cfg)

    # Program button held at power-on -> force setup mode
    forced = panel.program._raw() == 0
    if forced or not configmod.configured(cfg):
        run_portal(cfg, ring)
        return

    wlan = connect(cfg)
    have_time = False
    if wlan is not None:
        have_time = timeutil.sync_ntp()
        print("Clock: %s" % ("set over NTP" if have_time
                             else "NTP failed, demo mode"))
        show_ip(ring, cfg, wlan.ifconfig()[0])
    else:
        flash_count(ring, cfg, 3, colour=render.tint(0.3, warmth=1.0))

    server = None
    if wlan is not None:
        try:
            server = web.Server()
        except OSError:
            server = None

    # Manual mode addresses the four channels directly; W alone is a plain
    # white moon, which is the sensible thing to land on when you switch to it.
    manual_state = {"illum": 0.5, "waxing": True,
                    "r": 0.0, "g": 0.0, "b": 0.0, "w": 1.0}
    def status_text():
        """Short summary for the header of the control page."""
        if wlan is None:
            return "no Wi-Fi &ndash; demo mode"
        parts = ["connected to %s" % cfg["ssid"], wlan.ifconfig()[0]]
        try:
            parts.append("%d dBm" % wlan.status("rssi"))
        except Exception:
            pass
        parts.append("clock via NTP" if have_time else "no clock")
        return " &middot; ".join(parts)

    status = {"msg": status_text()}
    dirty_at = None
    calibrating = False
    # Programme time, in seconds with millisecond resolution.
    #
    # It must NOT come from time.time(): on MicroPython that returns whole
    # seconds as an integer, so every animation advanced in one-second jumps.
    # On the rainbow, at twelve seconds to a lap, that was a leap of three LED
    # positions at a time -- the thing looked like it was ticking rather than
    # turning. Accumulating from ticks_ms() also sidesteps the wrap that
    # ticks_ms() has on its own, which would otherwise put one jump in every
    # few days of running.
    prog_time = 0.0
    last_tick = ticks_ms()
    boot_at = time.time()
    frame_ms = int(1000 / cfg["fps"])
    last_frame = ticks_ms()
    last_sync = time.time()

    pending = {"calibrate": False, "reboot": False, "forget": False}

    def build_info():
        """Gather everything the page displays.

        Deliberately here and not in web.py: the page should compute nothing,
        so that loading it does not disturb the frame rate.
        """
        facts = [("Program", "P%d %s" % (cfg["program"],
                                          programs.NAMES[cfg["program"]])),
                 ("Brightness", "%.1f %%"
                  % (configmod.BRIGHTNESS_STEPS[cfg["brightness"]] * 100))]
        if wlan is not None:
            try:
                facts.append(("Signal", "%d dBm" % wlan.status("rssi")))
            except Exception:
                pass
            facts.append(("IP", wlan.ifconfig()[0]))
        if have_time:
            d = timeutil.utc_day_number()
            off = timeutil.local_offset_hours(cfg, d)
            lt = time.localtime(int(time.time() + off * 3600))
            facts.append(("Local time", "%02d:%02d" % (lt[3], lt[4])))
            facts.append(("Date", "%04d-%02d-%02d" % (lt[0], lt[1], lt[2])))
            try:
                p = ephemeris.moon_phase(d)
                facts.append(("Moon phase", "%.0f %% %s"
                              % (p["illum"] * 100,
                                 "waxing" if p["waxing"] else "waning")))
                facts.append(("Moon age", "%.1f days"
                              % (p["age"] * ephemeris.SYNODIC)))
                facts.append(("Distance", "%.0f km" % p["dist_km"]))
                alt, az = ephemeris.moon_altitude(d, cfg["latitude"],
                                                  cfg["longitude"])
                facts.append(("Moon altitude", "%+.1f deg %s"
                              % (alt, "above the horizon" if alt > 0
                                 else "below the horizon")))
            except Exception as exc:
                facts.append(("Ephemeris", "error: %s" % exc))
        else:
            facts.append(("Clock", "not set"))
        facts.append(("Uptime", "%d min" % int((time.time() - boot_at) / 60)))
        return {"status": status["msg"], "facts": facts,
                "manual": manual_state, "output": ring.describe()}

    def handler(path, query):
        if path == "/calibrate":
            pending["calibrate"] = True
            return "303 See Other", "text/html", _redirect()
        if path == "/reboot":
            pending["reboot"] = True
            return ("200 OK", "text/html",
                    "<!DOCTYPE html><meta charset='utf-8'>"
                    "<meta http-equiv='refresh' content='8; url=/'>"
                    "<p>Restarting ...</p>")
        if path == "/forget":
            cfg["ssid"] = ""
            cfg["password"] = ""
            configmod.save(configmod.validate(cfg))
            pending["reboot"] = True
            return ("200 OK", "text/html",
                    "<!DOCTYPE html><meta charset='utf-8'><p>Wi-Fi forgotten. "
                    "The lamp will restart and open the setup portal "
                    "'Moon Lamp Setup'.</p>")
        if path == "/set":
            if "program" in query:
                try:
                    cfg["program"] = max(0, min(programs.N_PROGRAMS - 1,
                                                int(query["program"])))
                except ValueError:
                    pass
            if "brightness" in query:
                try:
                    cfg["brightness"] = max(0, min(
                        len(configmod.BRIGHTNESS_STEPS) - 1,
                        int(query["brightness"])))
                except ValueError:
                    pass
            for key in ("illum", "r", "g", "b", "w"):
                if key in query:
                    try:
                        manual_state[key] = max(0.0, min(
                            1.0, float(query[key]) / 100.0))
                    except ValueError:
                        pass
            if "waxing" in query:
                manual_state["waxing"] = query["waxing"] not in ("0", "false")

            # --- ring geometry
            if "led_offset" in query:
                try:
                    cfg["led_offset"] = float(query["led_offset"]) % 360.0
                except ValueError:
                    pass
            if "led_clock" in query:
                # Clock position of pixel 0. Degrees remain the stored form;
                # this only names the positions the way a person would. Applied
                # after led_offset deliberately: if both ever arrive together,
                # the one the user actually looked at should win.
                try:
                    cfg["led_offset"] = render.clock_to_angle(
                        int(query["led_clock"]))
                except ValueError:
                    pass
            if "nudge" in query:
                # One LED pitch, so the ring can be turned pixel by pixel while
                # watching the lamp
                try:
                    step = 360.0 / max(1, int(cfg["led_count"]))
                    cfg["led_offset"] = ((cfg["led_offset"]
                                          + float(query["nudge"]) * step)
                                         % 360.0)
                except ValueError:
                    pass
            if "earthshine" in query:
                # Slider carries tenths of a percent
                try:
                    cfg["earthshine"] = max(0.0, min(0.2,
                                                     int(query["earthshine"])
                                                     / 1000.0))
                except ValueError:
                    pass
            if "led_clockwise" in query:
                cfg["led_clockwise"] = query["led_clockwise"] not in ("0", "false")

            if "temporal" in query or "subframes" in query:
                want = cfg.get("temporal")
                subs = int(cfg.get("subframes", 8))
                if "temporal" in query:
                    want = query["temporal"] not in ("0", "false")
                if "subframes" in query:
                    try:
                        subs = max(2, min(16, int(query["subframes"])))
                    except ValueError:
                        pass
                if want != cfg.get("temporal") or subs != cfg.get("subframes"):
                    # The DMA channel and the subframe buffers are set up once
                    # at start-up, so this takes effect after a restart.
                    cfg["temporal"] = want
                    cfg["subframes"] = subs
                    configmod.save(configmod.validate(cfg))
                    pending["reboot"] = True
                    return ("200 OK", "text/html",
                            "<!DOCTYPE html><meta charset='utf-8'>"
                            "<meta http-equiv='refresh' content='9; url=/'>"
                            "<p>Output mode changed. Restarting ...</p>")

            if "led_count" in query:
                try:
                    new_count = max(1, min(300, int(query["led_count"])))
                except ValueError:
                    new_count = cfg["led_count"]
                if new_count != cfg["led_count"]:
                    # The output buffer and the PIO state machine are set up
                    # once at start-up, so this only takes effect after a
                    # restart. Save immediately -- a reboot would drop a
                    # pending write.
                    cfg["led_count"] = new_count
                    configmod.save(configmod.validate(cfg))
                    pending["reboot"] = True
                    return ("200 OK", "text/html",
                            "<!DOCTYPE html><meta charset='utf-8'>"
                            "<meta http-equiv='refresh' content='9; url=/'>"
                            "<p>Now %d LEDs. Restarting ...</p>" % new_count)

            if "program" in query:
                pending["stop_calibrate"] = True
            pending["save"] = True
            return "303 See Other", "text/html", _redirect()
        return "200 OK", "text/html", web.control_page(cfg, build_info())

    while True:
        now = ticks_ms()
        prog_time += ticks_diff(now, last_tick) / 1000.0
        last_tick = now
        if ticks_diff(now, last_frame) < frame_ms:
            # Between image updates: keep the subframes going and serve HTTP.
            # tick() returns immediately unless the DMA path is idle, so this
            # costs nothing on the blocking path.
            ring.tick()
            if server is not None:
                server.poll(handler)
            continue
        last_frame = now

        # Carry out web-triggered actions in step with the loop
        if pending.get("reboot"):
            time.sleep(1)
            _reset()
        if pending.pop("calibrate", False):
            calibrating = True
        if pending.pop("stop_calibrate", False):
            calibrating = False
        if pending.pop("save", False):
            dirty_at = now

        for name, kind in panel.poll(now):
            if calibrating:
                if name == "program":
                    calibrating = False
                    dirty_at = now
                elif name == "up":
                    cfg["led_offset"] = (cfg["led_offset"] + 360.0
                                         / cfg["led_count"]) % 360.0
                elif name == "down":
                    cfg["led_offset"] = (cfg["led_offset"] - 360.0
                                         / cfg["led_count"]) % 360.0
                continue

            if name == "program" and kind == buttonsmod.LONG:
                calibrating = True
                continue
            if name == "program":
                cfg["program"] = (cfg["program"] + 1) % programs.N_PROGRAMS
                flash_count(ring, cfg, cfg["program"] + 1)
                prog_time = 0.0
            elif name == "up":
                cfg["brightness"] = min(len(configmod.BRIGHTNESS_STEPS) - 1,
                                        cfg["brightness"] + 1)
            elif name == "down":
                cfg["brightness"] = max(0, cfg["brightness"] - 1)
            dirty_at = now

        level = configmod.BRIGHTNESS_STEPS[cfg["brightness"]]
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

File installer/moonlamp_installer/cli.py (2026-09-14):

"""Console front end.

Everything the window can do, without the window -- useful over SSH, in a
workshop, and for anyone who would rather see what is happening.

    moonlamp-installer                 guided install, asks as it goes
    moonlamp-installer status          what is attached and what is on it
    moonlamp-installer update          newest firmware onto an installed board
    moonlamp-installer install --port COM5 --ssid Net --password secret
"""

import argparse
import os
import sys

from . import device
from . import install
from . import releases

BAR = 34


def report(stage, done, total, text):
    if done is not None and total:
        filled = int(BAR * done / float(total))
        sys.stdout.write("\r  %-13s [%s%s] %3d %%  %-24s"
                         % (stage, "#" * filled, "." * (BAR - filled),
                            100 * done / total, text[:24]))
        if done >= total:
            sys.stdout.write("\n")
    else:
        sys.stdout.write("\r  %-13s %-58s\n" % (stage, text))
    sys.stdout.flush()


def _print_bundled():
    uf2 = releases.bundled_uf2()
    print("  Bundled     : firmware %s%s"
          % (releases.bundled_version(),
             ", MicroPython " + os.path.basename(uf2) if uf2 else
             ", no MicroPython build"))


def cmd_status(args):
    state = install.survey(report)
    print()
    if not state["boards"] and not state["bootsel_drive"]:
        _print_bundled()
        print()
        print("No Raspberry Pi board found on USB.")
        print("If one is plugged in, it may need a data cable rather than a")
        print("charging cable -- those look identical and carry no data.")
        return 1
    for port, pid, what in state["boards"]:
        print("  %-10s USB 2E8A:%04X  %s" % (port, pid, what))
    if state["bootsel_drive"]:
        info = state["board_info"]
        print("  %-10s BOOTSEL drive, board %s"
              % (state["bootsel_drive"], info.get("Board-ID", "unknown")))
    if state["micropython"]:
        print("  MicroPython : %s" % state["micropython"])
        print("  Wi-Fi       : %s" % ("yes" if state.get("wifi") else
                                      "no radio -- this is not a W board"))
    if state["firmware"]:
        print("  Firmware    : %s" % state["firmware"])
        rel, why = install.check_for_update(state["firmware"],
                                            args.prereleases)
        if rel:
            print("  Update      : %s available (%s)" % (rel["version"], why))
        else:
            print("  Update      : %s" % why)
    elif state["repl_port"]:
        print("  Firmware    : not installed")
    _print_bundled()
    return 0


def _ensure_board(args):
    """Get to a board with MicroPython on it, flashing if need be."""
    port = args.port or device.find_repl_port()
    if port:
        return port

    drive = device.find_bootsel_drive()
    if not drive:
        print()
        print("No board with MicroPython found. To put it there:")
        print("  1. Unplug the Pico")
        print("  2. Hold BOOTSEL down and plug it back in, still holding")
        print("  3. Release -- a drive called RPI-RP2 appears")
        print()
        print("Waiting for that drive ...")
        drive = device.wait_for_bootsel(120.0)
        if not drive:
            raise SystemExit("gave up waiting for a board in BOOTSEL mode")
    return install.flash_micropython(args.uf2, drive, report)


def _settings_from_args(args):
    out = {}
    for key, val in (("ssid", args.ssid), ("password", args.password),
                     ("hostname", args.hostname),
                     ("latitude", args.lat), ("longitude", args.lon),
                     ("utc_offset", args.utc_offset),
                     ("led_count", args.leds), ("led_pin", args.led_pin)):
        if val is not None:
            out[key] = val
    if args.pixel_clock is not None:
        out["led_offset"] = install.clock_to_angle(args.pixel_clock)
    return out


def cmd_install(args):
    port = _ensure_board(args)
    files = releases.bundled_firmware()
    if args.online:
        rel = releases.latest_release(args.prereleases)
        if rel and releases.is_newer(rel["version"],
                                     releases.version_of(files)):
            print("  fetching firmware %s from GitHub" % rel["version"])
            files = install.fetch_firmware(rel)
    install.install_firmware(port, files, report)

    settings = _settings_from_args(args)
    if settings:
        install.write_config(port, settings, report=report)
    elif not args.code_only:
        print()
        print("  No Wi-Fi given, so setup happens on a phone:")
        print("    power the lamp, join the network 'Moon Lamp Setup',")
        print("    then open http://192.168.4.1")
    install.restart(port, report)
    print()
    print("Done.")
    return 0


def cmd_update(args):
    port = args.port or device.find_repl_port()
    if not port:
        raise SystemExit("no board with MicroPython found -- run 'install'")
    state = install.survey()
    installed = state.get("firmware")
    print("  installed: %s" % (installed or "nothing"))

    rel, why = install.check_for_update(installed, args.prereleases)
    if not rel and not args.force:
        print("  %s" % why)
        return 0
    if rel:
        print("  updating to %s (%s)" % (rel["version"], why))
        files = install.fetch_firmware(rel)
    else:
        print("  forcing a reinstall of the bundled firmware")
        files = releases.bundled_firmware()

    install.install_firmware(port, files, report)
    install.restart(port, report)
    print()
    print("Done. The configuration was left untouched.")
    return 0


def cmd_config(args):
    """Show what is on the lamp, without changing any of it."""
    port = args.port or device.find_repl_port()
    if not port:
        raise SystemExit("no board with MicroPython found")
    cfg = install.read_config(port)
    if not cfg:
        print("  The lamp has no config.json yet.")
        return 0
    for key in sorted(cfg):
        val = cfg[key]
        if key == "password":
            val = ("set, %d characters" % len(val)) if val else "empty"
        elif key == "led_offset":
            val = "%g deg -- %d o'clock" % (val, install.angle_to_clock(val))
        print("  %-12s: %s" % (key, val))
    return 0


def cmd_releases(args):
    for rel in releases.list_releases(args.prereleases):
        mark = " (pre-release)" if rel["prerelease"] else ""
        print("  %-10s %s%s" % (rel["version"], rel["name"] or "", mark))
        if not rel["asset"]:
            print("             no firmware archive attached")
    return 0
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

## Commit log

2026-09-13 Initial commit: moon lamp firmware, STL tooling and frame CAD
    A 3D-printed wall lamp that shows the real current moon phase. The relief is
    domed by 20 mm so that grazing light from the LED ring cannot cross to the far
    side, which is what turns a brightness gradient into an actual terminator:
    measured shadow-side light drops from about 10 % on the flat relief to below
    0.01 %.
    Contents:
    * firmware/ MicroPython for the Raspberry Pi Pico W. Ephemeris, arc rendering,
    spatial and temporal dithering, SK6812 RGBW driver over PIO with
    an optional DMA path, AP setup portal and a web interface.
    Six programs, three buttons.
    * tools/ Parametric STL warping, B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
    [frame-body.3mf, frame.FCStd, framev3-frame4x.3mf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]
2026-09-13 Translate the documentation to English and fix the paths after the move
    Both READMEs were still German, and carried numbers from before the strip
    changed: 44 LEDs at 30 mm pitch instead of 40 at 33 mm, a power figure to
    match, and a standing warning that the firmware had never run on hardware.
    That last one stopped being true some time ago.
    The tool scripts resolved their default paths relative to the old flat project
    folder, so after the reorganisation they pointed at a full.stl that is no
    longer there. stl_common now defines the layout once (ROOT, SOURCE_STL,
    GENERATED_DIR, PREVIEW_DIR) and every script derives from it, which also means
    they no longer care what the working directory is.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
2026-09-13 Keep real network details out of the published documentation
    The README's troubleshooting example and the rendered sample control page both
    carried the actual home network name and LAN address they were captured from.
    Replaced with a generic name and an address from the documentation range
    (192.0.2.0/24, RFC 5737), which is reserved for exactly this.
    The sample page was also still German and showed brightness steps from before
    the gamma fix. It is now generated by firmware/tools/render_sample_page.py from
    synthetic values shaped like main.build_info() output, so it can be refreshed
    whenever the page changes instead of being a stale capture.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
    [render_sample_page.py]
2026-09-13 Reduce the repository to the published project
    tools/ and preview/ are no longer tracked. The renders were 20 of the 22 MB
    here and only documented how the geometry was chosen; the STL scripts are still
    useful for retuning the dome, but they are working files rather than part of
    the release, and they need the 176 MB source STL to do anything at all.
    calibrate_arc.py and preview_firmware.py go with them: both import stl_common
    from tools/ and would be dead on arrival in a clone. The remaining four test
    suites need nothing but CPython.
    Documentation follows: the regeneration instructions are gone from the root
    README, models/README.md now simply points at Printables for the printable
    files,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
2026-09-13 Restore the Printables link and point the model docs at it
    Recovers the one part of the "Update README" commit made on GitHub that the
    history rewrite dropped. Its other two changes -- removing the preview
    reference and the regeneration section -- were the same edits made here, so
    they survive; only the link to the published model was unique to it.
    models/README.md pointed at the upstream remix for the printable files, which
    was wrong: that is the attribution chain, not the download. It now points at
    the published model, and the chain stays in LICENSE-MODELS.md where it belongs.
2026-09-13 Version the firmware and add a release build
    There was no version string anywhere, which is a problem once a Pico is on the
    wall: nothing on the lamp could say what was running on it. moonlight.VERSION
    is now the single place it lives, and both the web page footer and status.py
    report it.
    tools/make_release.py builds dist/moonlamp-firmware-<VERSION>.zip from that
    version: the code that runs on the Pico, the two scripts that talk to it, the
    firmware README and the licence. Test suites, the translation helpers and the
    page renderer stay in the repository and out of the archive. Line endings are
    normalised to LF so the archive is byte-identical wherever it is built.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
    [status.py]
2026-09-13 Refresh the sample page so it shows the firmware version
2026-09-14 Add a saturated colour program, rework manual mode, name pixel 0 by the clock
    Four changes to the firmware, all from using the lamp:
    P6 Spectrum is new: the full colour wheel at saturation, one turn every seven
    minutes. render.saturate() is what makes it different from P3 -- the cosine
    wheel is only fully saturated at six hues and washed out by up to 0.25 in
    between, so without taking the common minimum out, "full colour" would still
    look pastel.
    P3 was too timid to read as a colour change from across a room. Its coloured
    share goes from 45 % to 62 %, which puts peak chroma at 0.54 instead of 0.39.
    White still carries more than a third, which is what keeps the disc a moon
    rather than a lam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
    [main.py, render_sample_page.py]
2026-09-14 Add a single-executable installer and updater
    Takes a factory-fresh Pico W to a running lamp and updates it afterwards. It
    carries the firmware and a MicroPython build inside it, so it needs no Python,
    no pip and no network -- and the same tool pulls newer firmware from this
    repository's releases when there is a connection.
    It speaks the MicroPython raw REPL protocol directly rather than driving
    mpremote. That is not a preference: frozen into a one-file build,
    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
2026-09-14 Check the chip family before flashing, and the radio afterwards
    The board check was wrong in the most common case. An RP2040 bootloader reports
    "Board-ID: RPI-RP2" for a Pico and a Pico W alike -- there is no W in it
    anywhere -- so board_wants_wifi_build() returned False for every genuine Pico W
    and the warning "does not look like a W variant" would have fired on nearly
    every install.
    What the bootloader does reveal is the chip family, and that turns out to be
    the more useful question. A UF2 carries a family id and the bootloader
    discards blocks that do not match, so flashing an RP2040 build onto a Pico 2
    writes nothing, changes nothing, and leaves a board sitting in BOOTSEL with no
    indicat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
    [cli.py, device.py, install.py]
2026-09-14 Stop waiting five seconds for every reply the board has already sent
    The firmware transfer took about ten minutes when it should take about a
    second, and none of it was the Pico's fault.
    _read_until() asked for a fixed 256 bytes per read. pyserial's read(n) waits
    for n bytes or for the port timeout, whichever comes first -- it does not
    return early just because the device went quiet. A raw REPL reply is roughly
    ten bytes ("OK", output, two separators, the prompt), so every single read sat
    out the full five-second timeout before handing those ten bytes over. At
    around 120 round trips for 87 kB of firmware, that is ten minutes of waiting
    and a few seconds of work.
    Now it takes what is alread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
    [device.py]
2026-09-14 Read the lamp's settings before offering to write over them
    The window had a hole worth closing. load_settings() ran only after a firmware
    install, so opening the app, going straight to the Settings tab and pressing
    Save wrote the form's hardcoded defaults -- hostname, 51.2/6.8, 40 LEDs, 6
    o'clock -- over whatever the lamp actually held. Worse, an empty password field
    counted as a value, so that same stray save took the lamp off the network, and
    the mistake would only surface minutes later when the clock failed to set.
    Now the existing config.json is read as soon as a board with firmware is
    found, the form shows those values rather than defaults, and only fields that
    genuinely differ are se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
    [cli.py, gui.py, install.py]
2026-09-14 Add a rainbow that turns around the ring, and make the manual colours reachable
    P7 Rainbow: the whole spectrum on the ring at once, one turn every twelve
    seconds. It is the only program that uses the ring as a ring, and it only works
    because of the dome -- on a flat relief every LED washes across the whole disc
    and the colours sum to a muddy white, whereas the 20 mm rise keeps each LED's
    light on its own side, so the wheel lands on the surface as a wheel. Hue
    follows the physical angle rather than the pixel index, so it turns the same
    way round whichever direction the strip was wired; the test pins that by
    mirroring the indices.
    The manual RGB sliders were not broken. Every value reaches th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
2026-09-14 Give the rainbow constant power per hue, so the gradient has no seams
    The rainbow banded and pulsed as it turned. Measuring it around the ring showed
    why: saturating the cosine wheel by taking out its common minimum produces the
    right hues but not the right brightness. The six pure primaries came out a
    third dimmer than the blends between them -- 33 % variation from LED to LED,
    which is exactly what "not seamless" looks like.
    render.hue_rgb() replaces it with a linear ramp red -> green -> blue -> red
    whose three channels always sum to one. That is what the Adafruit strandtest
    wheel does, and the reason that sketch looks smooth. Variation around the ring
    is now zero.
    P6 had the same flaw in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
2026-09-14 Let "Save and restart" restart even when there is nothing to save
    The button names two things. Once the settings were protected from accidental
    overwriting, pressing it with nothing changed did neither -- it printed
    "nothing written" and stopped, which reads as a dead button rather than as a
    safeguard.
    Now the write is conditional and the restart is not. The confirmation dialog
    only appears when something is actually going to be written.
    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
2026-09-14 Stop every animation from stepping once a second
    The rainbow moved in visible jumps, several LED positions at a time, about once
    a second. It was not the colour wheel and not the frame rate: programme time
    came from `time.time() - t_start`, and on MicroPython time.time() returns whole
    seconds as an integer. So `t` was a staircase, and every animation climbed it.
    At twelve seconds to a lap that is a third of a second per LED, so each tick
    threw the pattern forward by more than three LEDs. P0, P3 and P6 had the same
    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
2026-09-14 Release 0.2
    Firmware 0.2, installer 1.1.
    Three new programs since 0.1 (Spectrum, Rainbow, and a reworked Manual), pixel
    0 named as a clock position rather than an angle, and a single-executable
    installer that takes a blank Pico all the way to a running lamp.
    Two bugs worth naming, both invisible on a PC and both found by using the
    thing: programme time came from time.time(), which returns whole seconds on
    MicroPython, so every animation climbed a staircase; and the installer's serial
    reads asked for a fixed 256 bytes, which on pyserial means waiting out the full
    timeout for a ten-byte reply -- ten minutes to transfer 87 kB.
2026-09-14 Ship the MicroPython build in the repository, so CI can build a complete one
    The 0.2 tag failed CI, and the reason is worth stating plainly: the UF2 was
    gitignored on the reasoning that people should fetch it from micropython.org.
    That holds for a person and not for a build runner, which starts from a clean
    checkout and has no other way to obtain it.
    The visible symptom was one failing test. The real one was worse: had the test
    passed, every installer the CI produced would have shipped without MicroPython
    -- unable to do the single thing that justifies carrying a payload at all.
    So the 1.8 MB goes into version control, next to 13 MB of CAD that was never in
    question. Downloading it during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
2026-09-14 Anchor the ignore rules, and add the release script they swallowed
    The 0.2 release job failed because firmware/tools/make_release.py was not in
    the repository at all. It had been written, committed in spirit, and quietly
    dropped: .gitignore carried "tools/" from when the STL tooling was taken out,
    and an unanchored pattern matches every directory of that name at any depth --
    firmware/tools/ included.
    Nothing broke at the time because git keeps tracking files it already tracks,
    so provision.py and status.py stayed put and only newly added files vanished.
    The gap stayed invisible until a release ran from a clean checkout.
    Both patterns are now anchored to the repository root. The same trap w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
    [make_release.py]
2026-09-14 Build subframes only once the picture has stopped moving
    Temporal dithering was making the lamp worse, and the measurement on the chip
    says why. Building six subframes costs six dithers: 32 ms, against 13 ms for
    the picture itself. With a 16 ms frame budget the loop then never finishes
    early, so tick() ran once per frame rather than the dozens of times the scheme
    needs -- and the six subframes were each held for 50 ms. That is not averaging,
    it is strobing. A drifting rainbow lurched around the ring in thirds of a
    second, which is exactly what it was reported as.
    The fix is not a cleverer schedule but a cheaper question: has the frame
    stopped changing? A moon phase holds identical 16-bit va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
2026-09-14 Release 0.2.1
    Firmware 0.2.1. One fix, and it is the one that mattered in use: temporal
    dithering built its subframes on every frame, which cost more than the picture
    itself and left the loop no time to show them. Six subframes held for 50 ms
    each do not average, they strobe -- the rainbow lurched around the ring in
    thirds of a second. Subframes are now built only once a frame has held still,
    and anything moving gets a single dither.
2026-10-17 Send pages in pieces, so a fragmented heap cannot stop them
    The control page was built as one string of about 11 kB; the body alone
    needed a contiguous 8 kB block, which the Pico W heap -- cut up by the
    Wi-Fi stack -- sometimes lacks: "MemoryError: memory allocation failed,
    allocating 8392 bytes". Before 0.2.2 that showed only as a dropped
    connection.
    Pages are now a list of pieces of at most a few kilobytes, each encoded
    and sent on its own, and the heap is collected before a page is built.
2026-10-17 Release 0.2.3
    Firmware 0.2.3. One fix: the control page sometimes failed with a
    MemoryError, because it needed an 8 kB contiguous block that a fragmented
    Pico W heap does not always have. Pages now go out in small pieces.
